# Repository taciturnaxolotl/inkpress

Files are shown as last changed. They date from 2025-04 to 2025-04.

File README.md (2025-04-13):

# Inky

blueprint

> ### More deets coming soon 👀  
> An open-source, eink-based, rpi zero 2 w powered camera.

## Setup

Put raspberry pi os lite 64-bit onto an SD card using the Raspberry Pi Imager and in the configureation step make sure to 1) add your SSH key and 2) set the user:password to `ink:inkycamera`. Oh and also make sure to add your wifi creds so we can update and install packages.

Next you need to configure network over usb so we can ssh in easily and be able to access the photo webserver.

Before sticking the card into the rpi, navigate to the boot partition and edit:

`config.txt` - add to bottom:
```txt
dtoverlay=dwc2
```

and `cmdline.txt` - apphend to the only line:
```txt
modules-load=dwc2,g_ether
```

Create empty `ssh` file in boot partition to enable SSH or just click the button in the RPI Imager gui.

now ssh in:
```bash
ssh ink@inky.local
# Default password: inkycamera
```

The firmware instructions are in [`src/README.md`](src/README.md) or you can run the following to auto configure

```bash
sudo bash -c "$(curl -fsSL hack.club/crgqvn)"
```

## Build Notes

This was a very fun project to work on because it felt so open ended. I did the case in [onshape](https://cad.onshape.com/documents/cf1e24c66f7dd61abebe0cb7/w/6aa471fe8ad6f1c116b0e667/e/df957c19e601178ca97da17b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) and made it into as slim of a design as possible. The pretty blueprint was made by just taking an onshape drawing, swapping out the background color, changing all the line stroke colors to #D2E7F8, and then changing all the text fill to the same color.

The code is bundled into an iso that auto builds via github actions on release which makes it as simple as just flashing an sd card to get running.

## BOM

| Name | Price | Manufacturer/Buy Link |
|---|---|---|
| Mini to Standard Camera Adapter Cable - 38mm | $4.99 | [Vilros](https://vilros.com/products/mini-to-standard-camera-adapter-cable-22-way-0-5mm-pitch-15-way-1mm-pitch-for-raspberry-pi-5-and-zero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) |
| Raspberry Pi Zero 2 W | $15.00 | [Adafruit](https://www.adafruit.com/product/5291) |
| Raspberry Pi Camera Module - Standard (any version works) | $25.00 | [Adafruit](https://www.adafruit.com/product/5657) |

<p align="center">
	
</p>

<p align="center">
	<i><code>&copy 2025-present <a href="https://github.com/taciturnaxolotl">Kieran Klukas</a></code></i>
</p>

<p align="center">
	
</p>

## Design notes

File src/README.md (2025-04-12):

### Installing and Setting Up the Camera Server

First, ensure you have the camera module enabled and working:

```bash
rpicam-still -o image.jpg 
```

Next, create the camera service file:

```bash
sudo vi /etc/systemd/system/camera.service
```

Create a directory for storing photos:

```bash
mkdir photos
```

Install required Python packages:

```bash
sudo apt update
sudo apt install python3-picamera2
sudo apt install python3-websockets
```

Finally start the camera service:

```bash
sudo systemctl daemon-reload
sudo systemctl enable camera.service
sudo systemctl start camera.service
```

You can check the status with:

```bash
sudo systemctl status camera
```

Or run the camera server directly with:

```bash
python3 camera_server.py
```

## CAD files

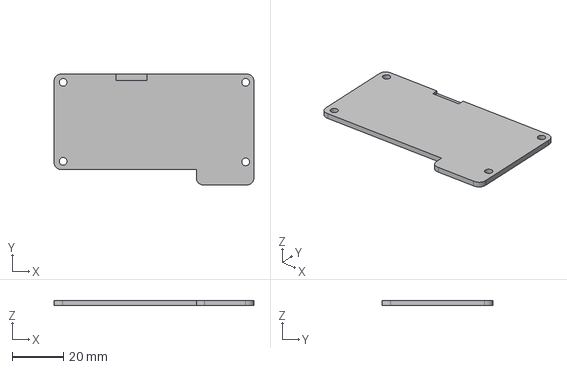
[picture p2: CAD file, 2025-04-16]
cad/inky-cover.step
77.9 x 43.3 x 2.00 mm

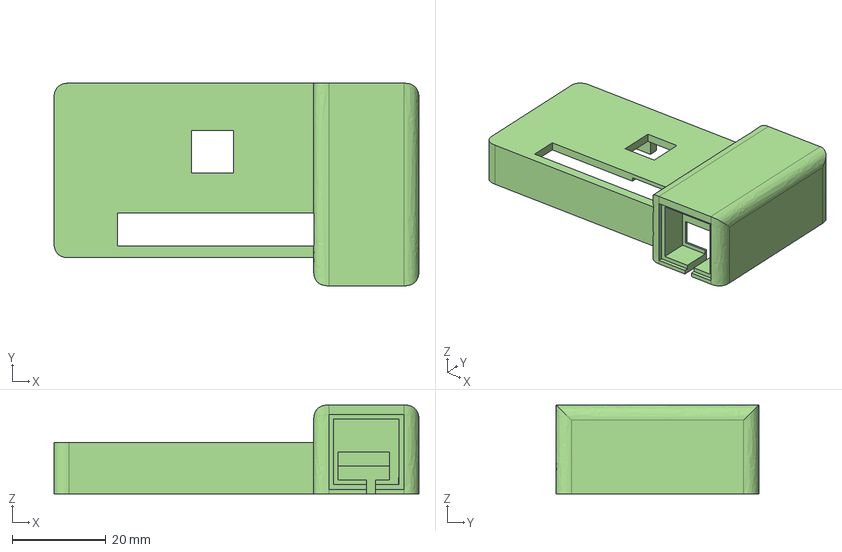
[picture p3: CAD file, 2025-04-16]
cad/inky-body.step
77.9 x 43.3 x 19.0 mm

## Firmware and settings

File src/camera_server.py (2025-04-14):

import RPi.GPIO as GPIO
import time
from picamera2 import Picamera2
from datetime import datetime
import os
import logging
import http.server
import socketserver
import threading
import websockets
import asyncio
import json

# Setup logging
logger = logging.getLogger('camera_server')
logger.setLevel(logging.INFO)
formatter = logging.Formatter('%(asctime)s - %(name)s - %(levelname)s - %(message)s')
file_handler = logging.FileHandler('/home/ink/camera_server.log')
file_handler.setFormatter(formatter)
stream_handler = logging.StreamHandler()
stream_handler.setFormatter(formatter)
logger.addHandler(file_handler)
logger.addHandler(stream_handler)

class Config:
    BUTTON_PIN = 2
    PHOTO_DIR = "/home/ink/photos"
    WEB_PORT = 80
    WS_PORT = 8765
    PHOTO_RESOLUTION = (1280, 960)
    CAMERA_SETTLE_TIME = 1
    DEBOUNCE_DELAY = 0.2
    POLL_INTERVAL = 0.01
    ROTATION = 90

def validate_photo_dir():
    if not os.path.isabs(Config.PHOTO_DIR):
        raise ValueError("PHOTO_DIR must be an absolute path")
    if not os.access(Config.PHOTO_DIR, os.W_OK):
        raise PermissionError(f"No write access to {Config.PHOTO_DIR}")

# Ensure photo directory exists and is valid
validate_photo_dir()
os.makedirs(Config.PHOTO_DIR, exist_ok=True)

# Set up GPIO
GPIO.setmode(GPIO.BCM)
GPIO.setup(Config.BUTTON_PIN, GPIO.IN)

# WebSocket clients set
connected_clients = set()

# Create a simple HTML gallery template - using triple quotes properly and making sure to escape curly braces
HTML_TEMPLATE = """<!DOCTYPE html>
<html>
<head>
    <title>Inky: Gallery</title>
    <meta name="viewport" content="width=device-width, initial-scale=1">
    <style>
        body {{ font-family: Arial; max-width: 800px; margin: 0 auto; padding: 20px; }}
        h1 {{ text-align: center; }}
        .gallery {{ display: flex; flex-wrap: wrap; gap: 10px; justify-content: center; }}
        .photo {{ border: 1px solid #ddd; padding: 5px; flex: 0 1 200px; position: relative; display: flex; flex-direction: column }}
        .photo img {{ width: 100%; height: 100%; object-fit: cover; }}
        .photo .colored-img {{ position: absolute; top: 5px; left: 5px; opacity: 0; pointer-events: none; width: calc(100% - 10px); height: calc(100% - 10px); }}
        .dithered-img:hover {{ opacity: 0; }}
        .dithered-img:hover + .colored-img {{ opacity: 1; }}
        .photo .actions {{ text-align: center; margin-top: 5px; }}
        .photo .actions a {{ margin: 0 5px; }}
        @keyframes fadeOut {{ from {{ opacity: 1; }} to {{ opacity: 0; }} }}
    </style>
    <script>
        let ws;
        const RECONNECT_DELAY = 1000;

        function connect() {{
            ws = new WebSocket('ws://' + window.location.hostname + ':8765');

            ws.onmessage = function(event) {{
                const data = JSON.parse(event.data);

                if (data.action === 'new_photo') {{
                    addPhoto(data.filename, data.timestamp);
                }} else if (data.action === 'delete_photo') {{
                    removePhoto(data.filename);
                }}
            }};

            ws.onclose = function() {{
                console.log('WebSocket connection closed. Reconnecting...');
                setTimeout(connect, RECONNECT_DELAY);
            }};

            ws.onerror = function(err) {{
                console.error('WebSocket error:', err);
                ws.close();
            }};
        }}

        connect();

        function addPhoto(filename, timestamp) {{
            const gallery = document.querySelector('.gallery');
            const noPhotosMsg = gallery.querySelector('p');
            if (noPhotosMsg) {{
                noPhotosMsg.remove();
            }}

            const originalFilename = filename.replace('dithered_', 'photo_');
            const isDithered = filename.startsWith('dithered_');

            if (isDithered) {{
                const photoDiv = document.createElement('div');
                photoDiv.className = 'photo';
                photoDiv.id = `photo-${{filename}}`;

                photoDiv.innerHTML = `
                    <img class="dithered-img" src="/${{filename}}" alt="${{timestamp}}">
                    <img class="colored-img" src="/${{originalFilename}}" alt="${{timestamp}}">
                    <div class="actions">
                        <a href="/${{originalFilename}}" download>Download Color</a>
                        <a href="/${{filename}}" download>Download Dithered</a>
                        <a href="#" onclick="deletePhoto('${{filename}}', '${{originalFilename}}'); return false;">Delete</a>
                    </div>
                `;

                gallery.insertBefore(photoDiv, gallery.firstChild);
            }}
        }}

        function removePhoto(filename) {{
            const photoDiv = document.getElementById(`photo-${{filename}}`);
            if (photoDiv) {{
                setTimeout(() => {{
                    photoDiv.remove();
                    const gallery = document.querySelector('.gallery');
                    if (gallery.children.length === 0) {{
                        const noPhotosMsg = document.createElement('p');
                        noPhotosMsg.style = 'text-align: center;';
                        noPhotosMsg.textContent = 'No photos yet. Press the button to take a photo!';
                        gallery.appendChild(noPhotosMsg);
                    }}
                }}, 100);
            }}
        }}

        function deletePhoto(ditheredFilename, originalFilename) {{
            if (confirm('Are you sure you want to delete this photo?')) {{
                fetch('/delete/' + ditheredFilename, {{
                    method: 'POST'
                }}).then(response => {{
                    if(response.ok) {{
                        return fetch('/delete/' + originalFilename, {{ method: 'POST' }});
                    }}
                }}).then(response => {{
                    if(response.ok) {{
                        removePhoto(ditheredFilename);
                    }}
                }});
            }}
        }}
    </script>
</head>
<body>
    <h1>Inky: Gallery</h1>
    <div class="gallery">
        {photo_items}
    </div>
</body>
</html>
"""

class PhotoHandler(http.server.SimpleHTTPRequestHandler):
    def __init__(self, *args, **kwargs):
        super().__init__(*args, directory=Config.PHOTO_DIR, **kwargs)

    def do_GET(self):
        if self.path == '/':
            self.send_response(200)
            self.send_header('Content-type', 'text/html')
            self.send_header('X-Content-Type-Options', 'nosniff')
            self.send_header('X-Frame-Options', 'DENY')
            self.send_header('X-XSS-Protection', '1; mode=block')
            self.end_headers()

            # Generate photo gallery HTML
            photo_items = ""
            try:
                files = sorted(os.listdir(Config.PHOTO_DIR), reverse=True)
                for filename in files:
                    if filename.lower().endswith(('.jpg', '.jpeg', '.png')) and filename.startswith('dithered_'):
                        originalFilename = filename.replace('dithered_', 'photo_')
                        timestamp = filename.replace('dithered_', '').replace('.jpg', '')
                        photo_items += f"""
                        <div class="photo" id="photo-{filename}">
                            <img class="dithered-img" src="/{filename}" alt="{timestamp}">
                            <img class="colored-img" src="/{originalFilename}" alt="{timestamp}">
                            <div class="actions">
                                <a href="/{originalFilename}" download>Download Color</a>
                                <a href="/{filename}" download>Download Dithered</a>
                                <a href="#" onclick="deletePhoto('{filename}', '{originalFilename}'); return false;">Delete</a>
                            </div>
                        </div>
                        """

                if not photo_items:
                    photo_items = "<p style='grid-column: 1/-1; text-align: center;'>No photos yet. Press the button to take a photo!</p>"
            except Exception as e:
                logger.error(f"Error generating gallery: {str(e)}")
                photo_items = f"<p>Error loading photos: {str(e)}</p>"

            html = HTML_TEMPLATE.format(photo_items=photo_items)
            self.wfile.write(html.encode())
        else:
            super().do_GET()

    def do_POST(self):
        if self.path.startswith('/delete/'):
            filename = self.path[8:]  # Remove '/delete/' prefix
            file_path = os.path.join(Config.PHOTO_DIR, filename)

            try:
                if os.path.exists(file_path) and os.path.isfile(file_path):
                    os.remove(file_path)
                    logger.info(f"Deleted photo: {filename}")
                    self.send_response(200)
                    self.send_header('Content-type', 'text/plain')
                    self.end_headers()
                    self.wfile.write(b"File deleted successfully")
                    asyncio.run(notify_clients('delete_photo', {'filename': filename}))
                else:
                    self.send_response(404)
                    self.send_header('Content-type', 'text/plain')
                    self.end_headers()
                    self.wfile.write(b"File not found")
            except Exception as e:
                logger.error(f"Error deleting file {filename}: {str(e)}")
                self.send_response(500)
                self.send_header('Content-type', 'text/plain')
                self.end_headers()
                self.wfile.write(b"Error deleting file")
        else:
            self.send_response(404)
            self.end_headers()

async def websocket_handler(websocket, path):
    connected_clients.add(websocket)
    try:
        await websocket.wait_closed()
    finally:
        connected_clients.remove(websocket)

async def notify_clients(action, data):
    if connected_clients:
        message = {
            'action': action,
            **data
        }
        await asyncio.gather(
            *[client.send(json.dumps(message)) for client in connected_clients]
        )

def take_photo():
    """
    Captures a photo using the Raspberry Pi camera.

    The photo is saved with a timestamp in the configured photo directory.
    The camera is configured for still capture at the specified resolution.

    Raises:
        IOError: If there's an error accessing the camera or saving the file
    """
    try:
        with Picamera2() as picam2:
            config = picam2.create_still_configuration(main={"size": Config.PHOTO_RESOLUTION})
            picam2.configure(config)
            picam2.start()
            time.sleep(Config.CAMERA_SETTLE_TIME)

            timestamp = datetime.now().strftime("%Y-%m-%d_%H-%M-%S")
            filename = f"photo_{timestamp}.jpg"
            dithered_filename = f"dithered_{timestamp}.jpg"
            filepath = os.path.join(Config.PHOTO_DIR, filename)
            dithered_filepath = os.path.join(Config.PHOTO_DIR, dithered_filename)
            logger.info(f"Taking photo: {filepath}")

            picam2.capture_file(filepath)
            logger.info("Photo taken successfully")

            # Rotate the image using ImageMagick
            os.system(f"convert {filepath} -rotate {Config.ROTATION} {filepath}")
            logger.info("Photo rotated successfully")

            # Create dithered version using ImageMagick
            os.system(f"convert {filepath} -dither FloydSteinberg -define dither:diffusion-amount=100% -remap eink-4gray.png {dithered_filepath}")
            logger.info("Dithered version created successfully")

            # Notify websocket clients about both photos
            asyncio.run(notify_clients('new_photo', {
                'filename': dithered_filename,
                'timestamp': timestamp
            }))

    except IOError as e:
        logger.error(f"IO Error while taking photo: {str(e)}")
    except Exception as e:
        logger.error(f"Unexpected error while taking photo: {str(e)}")

def run_server():
    try:
        handler = PhotoHandler
        with socketserver.TCPServer(("", Config.WEB_PORT), handler) as httpd:
            logger.info(f"Web server started at port {Config.WEB_PORT}")
            httpd.serve_forever()
    except Exception as e:
        logger.error(f"Server error: {str(e)}")

def cleanup():
    try:
        # Instead of getting/creating a new loop, we'll work with the running loop
        loop = asyncio.get_running_loop()

        # Create a new event loop for cleanup operations if needed
        cleanup_loop = asyncio.new_event_loop()
        asyncio.set_event_loop(cleanup_loop)

        # Close all websocket connections
        for websocket in connected_clients.copy():
            cleanup_loop.run_until_complete(websocket.close())

        # Cancel all tasks in the main loop
        for task in asyncio.all_tasks(loop):
            task.cancel()

        cleanup_loop.close()

    except RuntimeError:
        # Handle case where there is no running loop
        logger.info("No running event loop found during cleanup")
    except Exception as e:
        logger.error(f"Error during cleanup: {str(e)}")

def main():
    logger.info("Camera and web server starting")
    server = None
    ws_server = None
    loop = None

    try:
        socketserver.TCPServer.allow_reuse_port = True

        # Start HTTP server
        server = socketserver.TCPServer(("", Config.WEB_PORT), PhotoHandler)
        server_thread = threading.Thread(target=server.serve_forever, daemon=True)
        server_thread.start()

        # Create new event loop for websockets
        loop = asyncio.new_event_loop()
        asyncio.set_event_loop(loop)

        # Start WebSocket server
        ws_server = websockets.serve(websocket_handler, "0.0.0.0", Config.WS_PORT)
        loop.run_until_complete(ws_server)
        ws_thread = threading.Thread(
            target=loop.run_forever,
            daemon=True
        )
        ws_thread.start()

        logger.info("Camera and web server started")

        previous_state = GPIO.input(Config.BUTTON_PIN)
        while True:
            current_state = GPIO.input(Config.BUTTON_PIN)

            if current_state == False and previous_state == True:
                logger.info("Button press detected")
                take_photo()
                time.sleep(Config.DEBOUNCE_DELAY)

            previous_state = current_state
            time.sleep(Config.POLL_INTERVAL)

    except KeyboardInterrupt:
        logger.info("Program stopped by user")
    except Exception as e:
        logger.error(f"Unexpected error: {str(e)}")
    finally:
        if server:
            server.shutdown()
            server.server_close()
        if loop:
            loop.stop()
        GPIO.cleanup()
        logger.info("GPIO cleaned up")
        cleanup()

if __name__ == "__main__":
    main()

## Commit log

2025-04-11 feat: add service and remove button
2025-04-12 chore: switch to inky user
2025-04-12 feat: add cad
    [bottom.step, top.step]
2025-04-12 docs: add bom and notes
2025-04-13 chore: replace inkpress with inky
    [camera_server.py]
2025-04-13 chore: change button pin
2025-04-13 bug: fix pullup resister
    [camera_server.py]
2025-04-14 feat: add new cad
    [bottom.step, inky-body.step, inky-cover.step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]
2025-04-14 chore: update body model
    [inky-body.step]
2025-04-14 bug: fix magick being old and using convert on rpi
    [camera_server.py]
2025-04-14 bug: fix color image not getting proper url
    [camera_server.py]
2025-04-14 chore: remove all starting animation and fix flex
    [camera_server.py]
2025-04-14 bug: only expand if hovering over the image
    [camera_server.py]
2025-04-16 chore: update case
    [inky-body.step, inky-cover.step]
